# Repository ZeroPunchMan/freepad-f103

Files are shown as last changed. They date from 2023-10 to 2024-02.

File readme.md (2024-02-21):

# 使用说明

## 校准步骤
```
1.松开全部按键和摇杆,长按配对键(USB插孔旁).
2.等LED出现呼吸灯效果,此时程序会等待摇杆和扳机稳定,并记录作为初始值.
3.一直等待至LED出现快速闪烁效果,此时表示初始值已记录完毕,开始记录边界值.
4.把左右扳机按到底部,同时把两个摇杆摇圈.
5.待LED变成呼吸灯效果后,再重复数次,短按A键并松开.
6.LED恢复常亮,校准完毕.
```

## 重置校准值
```
同上面校准步骤,但第4步改为如下操作:
4.按住Y键.
5.等LED恢复为常亮,校准值重置完毕.
```

## 升级固件步骤
```
1.拔掉手柄USB线.
2.按住配对键(USB插孔旁).
3.插入USB线.
4.观察到LED较慢闪烁,表明手柄已进入BOOT状态.
5.打开DFU软件,选择对应串口并打开.
6.选择APP固件及其签名,点击开始升级.
7.提示升级成功则完毕.
```

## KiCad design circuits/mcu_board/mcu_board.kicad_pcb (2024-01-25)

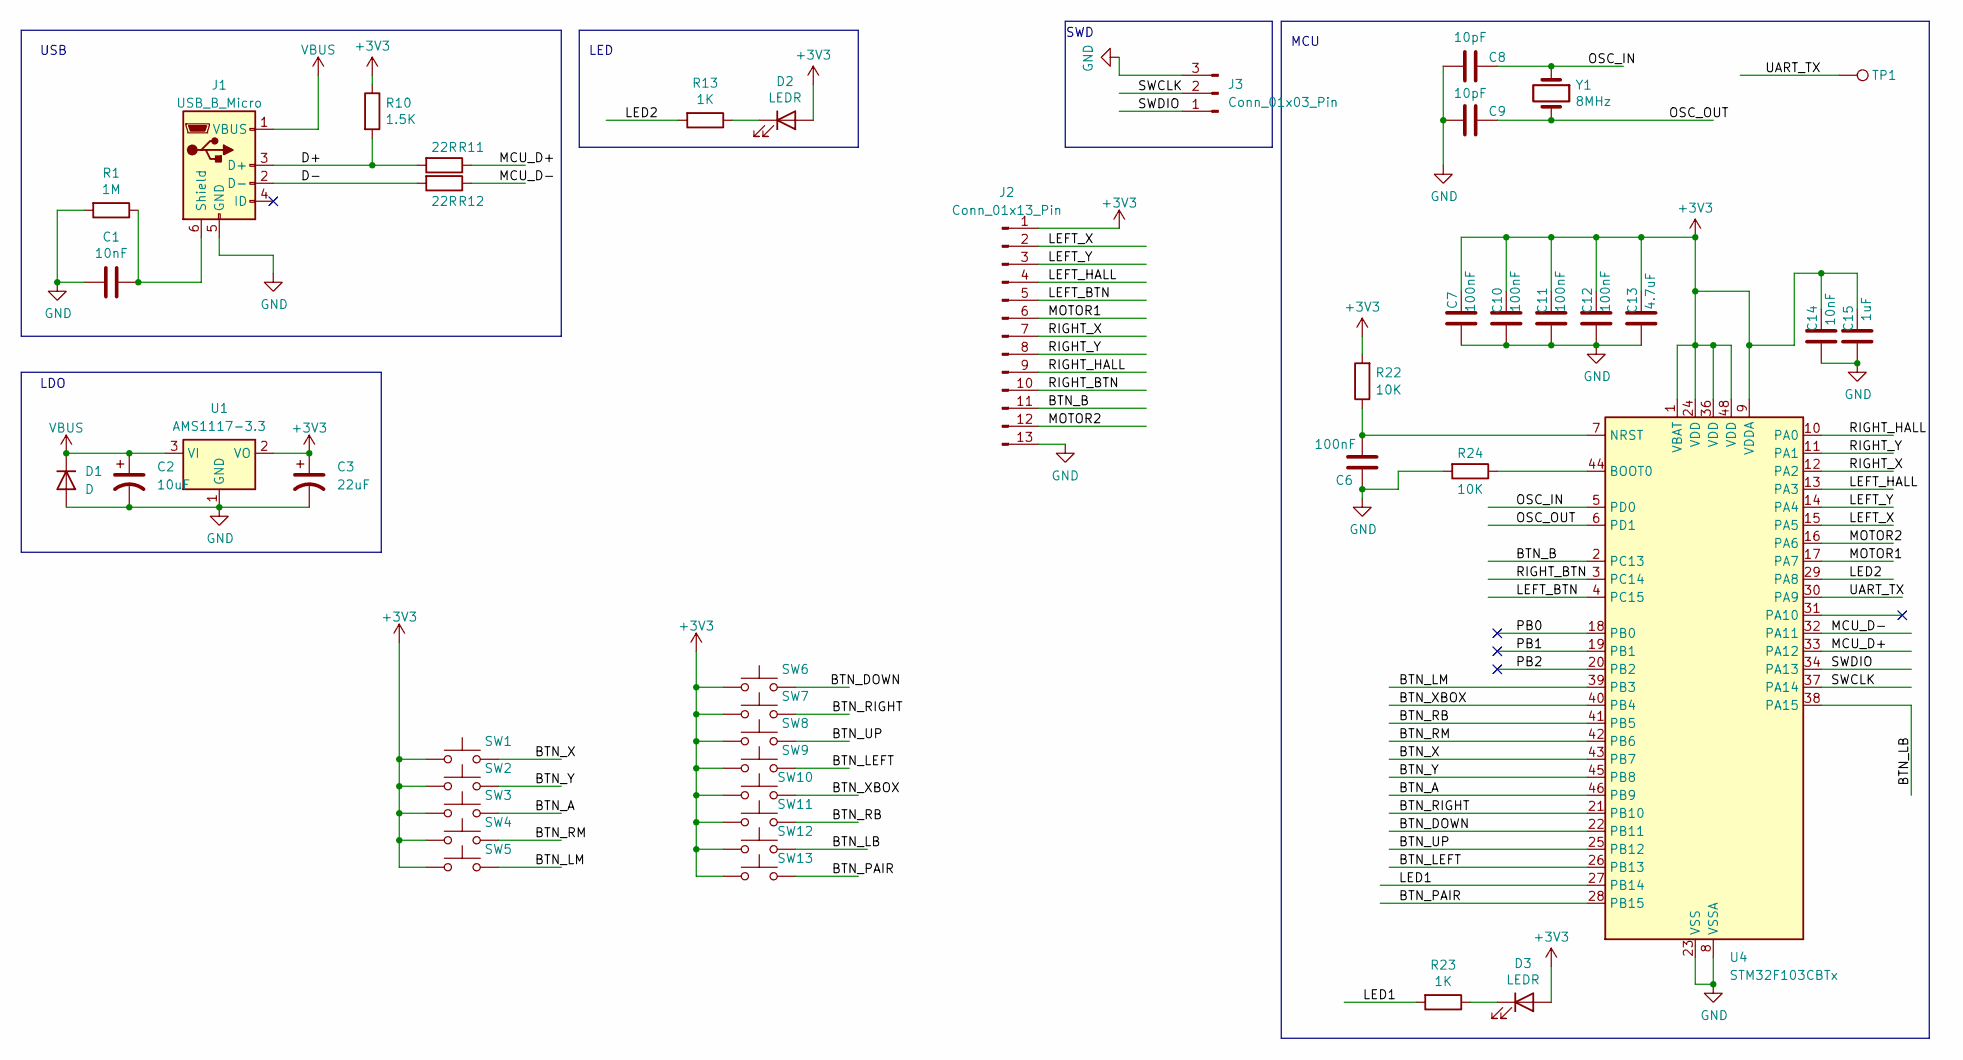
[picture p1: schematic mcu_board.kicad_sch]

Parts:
C1, C14: 10nF; C_0805_2012Metric_Pad1.18x1.45mm_HandSolder
C2: 10uF; C_1206_3216Metric_Pad1.33x1.80mm_HandSolder
C3: 22uF; C_1206_3216Metric_Pad1.33x1.80mm_HandSolder
C6, C7, C10, C11, C12: 100nF; C_0805_2012Metric_Pad1.18x1.45mm_HandSolder
C8, C9: 10pF; C_0805_2012Metric_Pad1.18x1.45mm_HandSolder
C13: 4.7uF; C_0805_2012Metric_Pad1.18x1.45mm_HandSolder
C15: 1uF; C_0805_2012Metric_Pad1.18x1.45mm_HandSolder
D1: D; D_2010_5025Metric_Pad1.52x2.65mm_HandSolder
D2, D3: LEDR; LED_0805_2012Metric_Pad1.15x1.40mm_HandSolder
J1: USB_B_Micro; USB_MICRO
J2: Conn_01x13_Pin; Molex_200528-0130_1x13-1MP_P1.00mm_Horizontal
J3: Conn_01x03_Pin; PinHeader_1x03_P2.54mm_Vertical
R1: 1M; R_0805_2012Metric_Pad1.20x1.40mm_HandSolder
R10: 1.5K; R_0805_2012Metric_Pad1.20x1.40mm_HandSolder
R11, R12: 22R; R_0805_2012Metric_Pad1.20x1.40mm_HandSolder
R13, R23: 1K; R_0805_2012Metric_Pad1.20x1.40mm_HandSolder
R22, R24: 10K; R_0805_2012Metric_Pad1.20x1.40mm_HandSolder
SW1, SW2, SW3, SW4, SW5: SW_Push; touch
SW6, SW7, SW8, SW9: SW_Push; touch-dpad
SW10: SW_Push; touch-xbox
SW11, SW12: SW_Push; click_lbrb
SW13: SW_Push; click_pair
TP1: TestPoint; TestPoint_Pad_1.0x1.0mm
U1: AMS1117-3.3; SOT-223-3_TabPin2
U4: STM32F103CBTx; LQFP-48_7x7mm_P0.5mm
Y1: 8MHz; Crystal_SMD_5032-2Pin_5.0x3.2mm_HandSoldering

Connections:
+3V3: C3.1, C7.1, C10.1, C11.1, C12.1, C13.1, C14.1, C15.1, D2.2 (A), D3.2 (A), J2.1, R10.1, R22.2, SW1.1, SW2.1, SW3.1, SW4.1, SW5.1, SW6.1, SW7.1, SW8.1, SW9.1, SW10.1, SW11.1, SW12.1, SW13.1, U1.2 (VO), U4.1 (VBAT), U4.9 (VDDA), U4.24 (VDD), U4.36 (VDD), U4.48 (VDD)
/BTN_A: SW3.2, U4.46 (PB9)
/BTN_B: J2.11, U4.2 (PC13)
/BTN_DOWN: SW6.2, U4.22 (PB11)
/BTN_LB: SW12.2, U4.38 (PA15)
/BTN_LEFT: SW9.2, U4.26 (PB13)
/BTN_LM: SW5.2, U4.39 (PB3)
/BTN_PAIR: SW13.2, U4.28 (PB15)
/BTN_RB: SW11.2, U4.41 (PB5)
/BTN_RIGHT: SW7.2, U4.21 (PB10)
/BTN_RM: SW4.2, U4.42 (PB6)
/BTN_UP: SW8.2, U4.25 (PB12)
/BTN_X: SW1.2, U4.43 (PB7)
/BTN_XBOX: SW10.2, U4.40 (PB4)
/BTN_Y: SW2.2, U4.45 (PB8)
/D+: J1.3 (D+), R10.2, R11.2
/D-: J1.2 (D-), R12.2
/LED1: R23.2, U4.27 (PB14)
/LED2: R13.2, U4.29 (PA8)
/LEFT_BTN: J2.5, U4.4 (PC15)
/LEFT_HALL: J2.4, U4.13 (PA3)
/LEFT_X: J2.2, U4.15 (PA5)
/LEFT_Y: J2.3, U4.14 (PA4)
/MCU_D+: R11.1, U4.33 (PA12)
/MCU_D-: R12.1, U4.32 (PA11)
/MOTOR1: J2.6, U4.17 (PA7)
/MOTOR2: J2.12, U4.16 (PA6)
/OSC_IN: C8.1, U4.5 (PD0), Y1.1
/OSC_OUT: C9.1, U4.6 (PD1), Y1.2
/PB0: U4.18 (PB0)
/PB1: U4.19 (PB1)
/PB2: U4.20 (PB2)
/RIGHT_BTN: J2.10, U4.3 (PC14)
/RIGHT_HALL: J2.9, U4.10 (PA0)
/RIGHT_X: J2.7, U4.12 (PA2)
/RIGHT_Y: J2.8, U4.11 (PA1)
/SWCLK: J3.2, U4.37 (PA14)
/SWDIO: J3.1, U4.34 (PA13)
/UART_TX: TP1.1, U4.30 (PA9)
GND: C1.2, C2.2, C3.2, C6.2, C7.2, C8.2, C9.2, C10.2, C11.2, C12.2, C13.2, C14.2, C15.2, D1.2 (A), J1.5 (GND), J2.13, J3.3, R1.2, R24.2, U1.1 (GND), U4.8 (VSSA), U4.23 (VSS), U4.35 (VSS), U4.47 (VSS)
unnamed: D2.1 (K), R13.1
unnamed: D3.1 (K), R23.1
unnamed: C1.1, J1.6 (Shield), R1.1
unnamed: R24.1, U4.44 (BOOT0)
unnamed: C6.1, R22.1, U4.7 (NRST)
VBUS: C2.1, D1.1 (K), J1.1 (VBUS), U1.3 (VI)

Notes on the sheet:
LDO
USB
SWD
MCU
LED

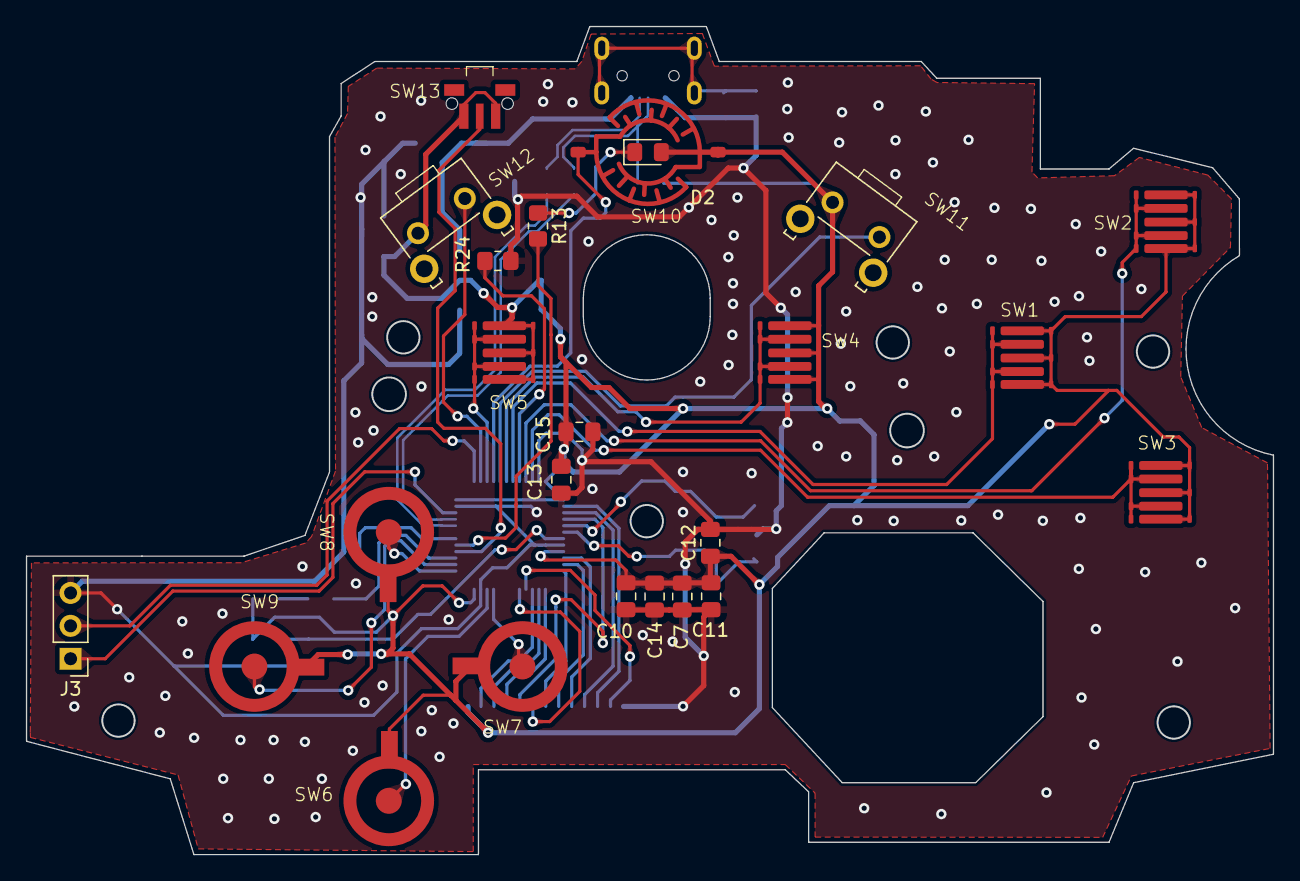
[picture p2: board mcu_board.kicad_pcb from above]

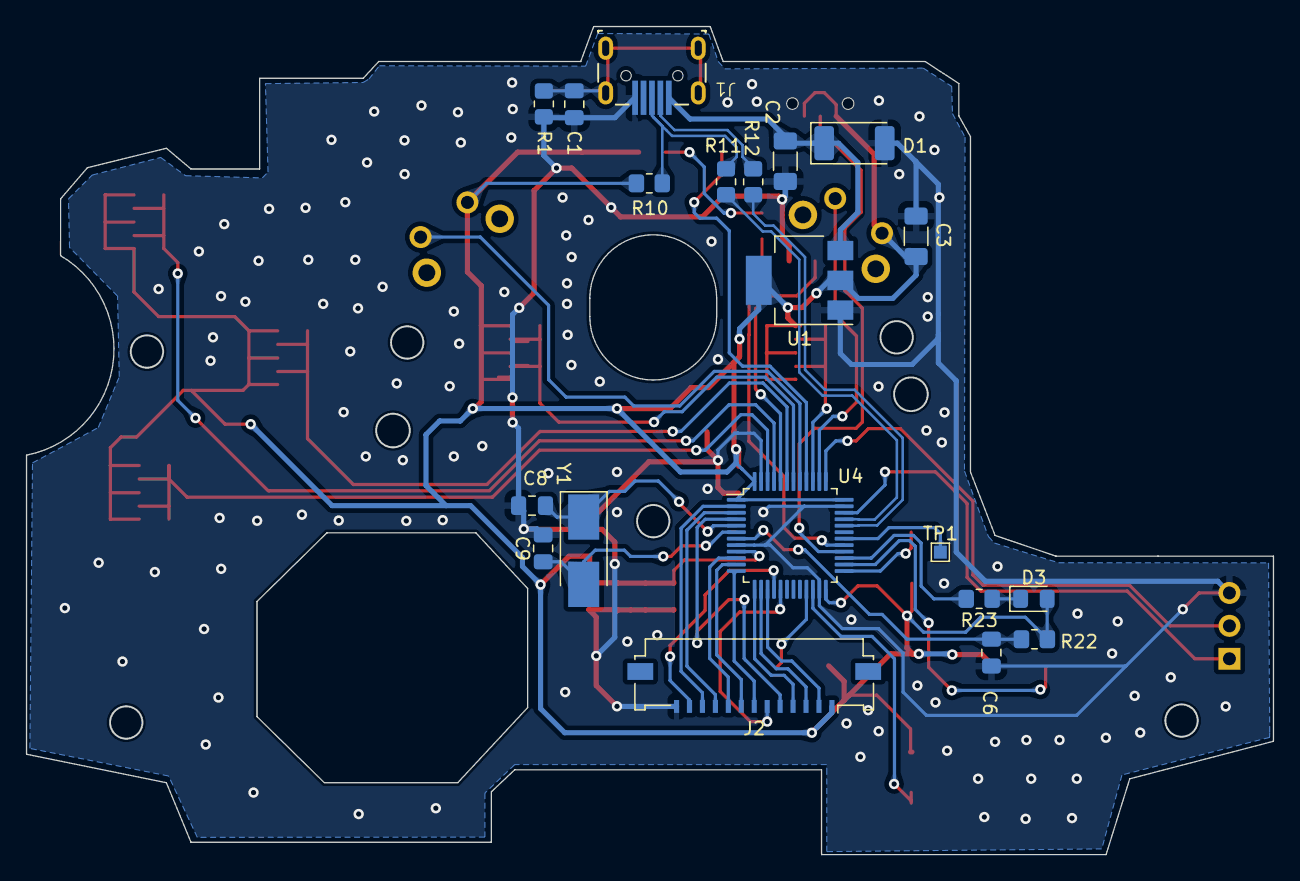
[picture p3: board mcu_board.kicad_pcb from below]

Board: 2 copper layers, 96.3 x 63.9 mm, 44 parts (20 on the bottom side), 43 nets.

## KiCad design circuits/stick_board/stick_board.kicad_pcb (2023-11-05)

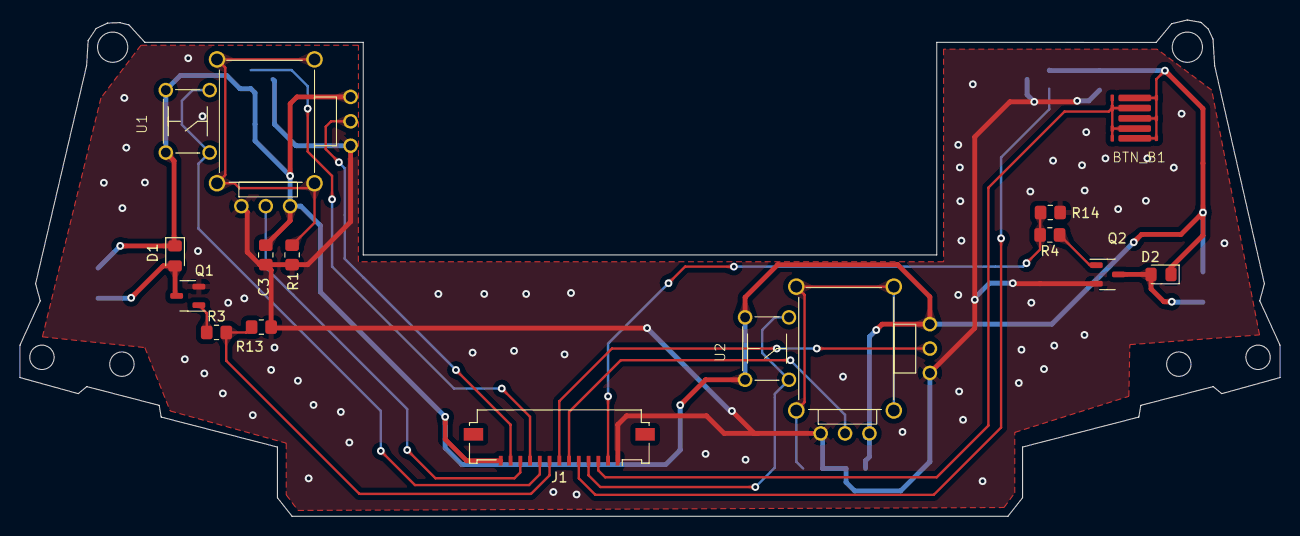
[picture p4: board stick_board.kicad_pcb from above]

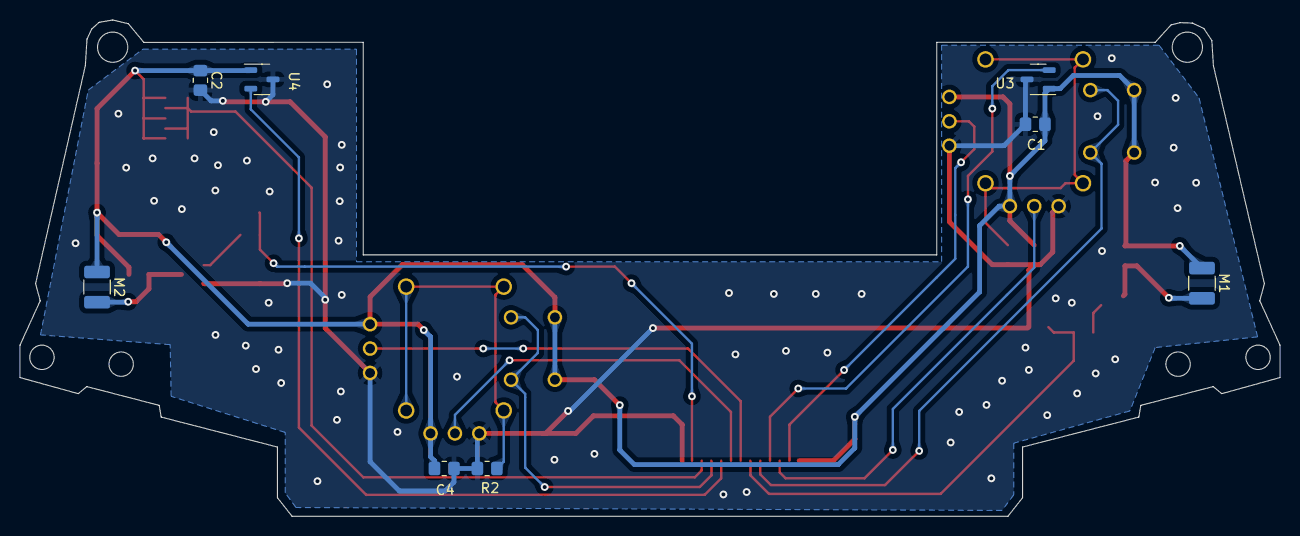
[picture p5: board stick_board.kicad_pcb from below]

Board: 2 copper layers, 129.2 x 50.9 mm, 22 parts (8 on the bottom side), 19 nets.

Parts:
BTN_B1: SW_PUSH; touch
C1, C2, C3, C4: 100nF; R_0805_2012Metric_Pad1.20x1.40mm_HandSolder
D1, D2: D; D_0805_2012Metric_Pad1.15x1.40mm_HandSolder
J1: Conn_01x13_Pin; Molex_200528-0130_1x13-1MP_P1.00mm_Horizontal
M1, M2: Motor_DC; R_1210_3225Metric_Pad1.30x2.65mm_HandSolder
Q1, Q2: AO3400A; SOT-23-3
R1, R2: 1M; R_0805_2012Metric_Pad1.20x1.40mm_HandSolder
R3, R4: 1K; R_0805_2012Metric_Pad1.20x1.40mm_HandSolder
R13, R14: 10K; R_0805_2012Metric_Pad1.20x1.40mm_HandSolder
U1, U2: GULI
U3, U4: DRV5055A1xDBZxQ1; SOT-23-3

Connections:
+3V3: BTN_B1.1, C1.1, C2.1, C3.1, C4.1, D1.1 (K), D2.1 (K), J1.13, M1.1 (+), M2.1 (+), U1.2 (VDD), U1.5 (SW_2), U2.2 (VDD), U2.5 (SW_2), U3.1 (VCC), U4.1 (VCC)
/BTN_B: BTN_B1.2, J1.3
/LEFT_BTN: J1.9, U1.4 (SW_1)
/LEFT_HALL: J1.10, U3.2 (OUT)
/LEFT_X: J1.12, U1.7 (X)
/LEFT_Y: J1.11, U1.6 (Y)
/MOTOR1: J1.8, R3.2, R13.2
/MOTOR2: J1.2, R4.2, R14.2
/RIGHT_BTN: J1.4, U2.4 (SW_1)
/RIGHT_HALL: J1.5, U4.2 (OUT)
/RIGHT_X: J1.7, U2.7 (X)
/RIGHT_Y: J1.6, U2.6 (Y)
GND: C1.2, C2.2, C3.2, C4.2, J1.1, Q1.2 (S), Q2.2 (S), R1.1, R2.1, R13.1, R14.1, U1.1 (GND), U2.1 (GND), U3.3 (GND), U4.3 (GND)
unnamed: D1.2 (A), M1.2 (-), Q1.3 (D)
unnamed: D2.2 (A), M2.2 (-), Q2.3 (D)
unnamed: Q1.1 (G), R3.1
unnamed: Q2.1 (G), R4.1
unnamed: R1.2, U1.3 (Shield)
unnamed: R2.2, U2.3 (Shield)

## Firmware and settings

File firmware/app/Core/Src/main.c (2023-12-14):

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
/* Includes ------------------------------------------------------------------*/
#include "main.h"
#include "adc.h"
#include "dma.h"
#include "tim.h"
#include "usart.h"
#include "usb_device.h"
#include "gpio.h"

/* USER CODE BEGIN Includes */
#include "systime.h"
#include "cl_log.h"
#include "cl_event_system.h"
#include "pad_func.h"
#include "led.h"
#include "button.h"
/* USER CODE END Includes */


void SystemClock_Config(void);
/* USER CODE BEGIN 0 */
static void UsbFakePlug(void)
{
  LL_APB2_GRP1_EnableClock(LL_APB2_GRP1_PERIPH_GPIOA);
  LL_GPIO_ResetOutputPin(GPIOA, LL_GPIO_PIN_12);

  LL_GPIO_InitTypeDef GPIO_InitStruct = {0};
  GPIO_InitStruct.Pin = LL_GPIO_PIN_12;
  GPIO_InitStruct.Mode = LL_GPIO_MODE_OUTPUT;
  GPIO_InitStruct.Speed = LL_GPIO_SPEED_FREQ_LOW;
  GPIO_InitStruct.OutputType = LL_GPIO_OUTPUT_OPENDRAIN;
  GPIO_InitStruct.Pull = LL_GPIO_PULL_UP;
  LL_GPIO_Init(GPIOA, &GPIO_InitStruct);

  LL_GPIO_ResetOutputPin(GPIOA, LL_GPIO_PIN_12);
  HAL_Delay(100);
  LL_GPIO_SetOutputPin(GPIOA, LL_GPIO_PIN_12);
}
/* USER CODE END 0 */

/**
  * @brief  The application entry point.
  * @retval int
  */
int main(void)
{
  /* USER CODE BEGIN 1 */
  CL_EventSysInit();
  /* USER CODE END 1 */

  /* MCU Configuration--------------------------------------------------------*/

  /* Reset of all peripherals, Initializes the Flash interface and the Systick. */
  HAL_Init();

  /* Configure the system clock */
  SystemClock_Config();

  /* USER CODE BEGIN SysInit */
  UsbFakePlug();
  /* USER CODE END SysInit */

  /* Initialize all configured peripherals */
  MX_GPIO_Init();
  MX_DMA_Init();
  MX_USART1_UART_Init();
  MX_USB_DEVICE_Init();
  MX_ADC1_Init();
  MX_TIM3_Init();
  MX_TIM1_Init();
  /* USER CODE BEGIN 2 */
  HAL_TIM_PWM_Start(&htim3, TIM_CHANNEL_1);
  HAL_TIM_PWM_Start(&htim3, TIM_CHANNEL_2);
  HAL_TIM_PWM_Start(&htim1, TIM_CHANNEL_1);
  /* USER CODE END 2 */

  /* Infinite loop */
  /* USER CODE BEGIN WHILE */
  Button_Init();
  Led_Init();
  PadFunc_Init();
  while (1)
  {
    Button_Process();
    Led_Process();
    PadFunc_Process();
    /* USER CODE END WHILE */

    /* USER CODE BEGIN 3 */
    static uint32_t lastTime = 0;
    if (SysTimeSpan(lastTime) >= 1000)
    {
      lastTime = GetSysTime();
      // CL_LOG_INFO("app2: %us", lastTime / 1000);
    }
  }
  /* USER CODE END 3 */
}

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


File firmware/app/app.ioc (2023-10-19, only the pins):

Mcu.UserName=STM32F103CBTx
PA0-WKUP.Signal=ADCx_IN0
PA1.Signal=ADCx_IN1
PA10.Signal=USART1_RX
PA11.Signal=USB_DM
PA12.Signal=USB_DP
PA15.Signal=GPIO_Input
PA2.Signal=ADCx_IN2
PA3.Signal=ADCx_IN3
PA4.Signal=ADCx_IN4
PA5.Signal=ADCx_IN5
PA6.Signal=S_TIM3_CH1
PA7.Signal=S_TIM3_CH2
PA8.Signal=S_TIM1_CH1
PA9.Signal=USART1_TX
PB10.Signal=GPIO_Input
PB11.Signal=GPIO_Input
PB12.Signal=GPIO_Input
PB13.Signal=GPIO_Input
PB14.Signal=GPIO_Output
PB15.Signal=GPIO_Input
PB3.Signal=GPIO_Input
PB4.Signal=GPIO_Input
PB5.Signal=GPIO_Input
PB6.Signal=GPIO_Input
PB7.Signal=GPIO_Input
PB8.Signal=GPIO_Input
PB9.Signal=GPIO_Input
PC13-TAMPER-RTC.Signal=GPIO_Input
PC14-OSC32_IN.Signal=GPIO_Input
PC15-OSC32_OUT.Signal=GPIO_Input
PD0-OSC_IN.Signal=RCC_OSC_IN
PD1-OSC_OUT.Signal=RCC_OSC_OUT

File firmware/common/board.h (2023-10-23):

#pragma once

#include "main.h"

#define GPIO_APB (LL_APB2_GRP1_PERIPH_GPIOB)

#define STA_LED_PROT (GPIOB)
#define STA_LED_PIN (LL_GPIO_PIN_14)

//**************按键****************
#define BTN_B_PORT (GPIOC)
#define BTN_B_PIN (LL_GPIO_PIN_13)

#define BTN_RSTICK_PORT (GPIOC)
#define BTN_RSTICK_PIN (LL_GPIO_PIN_14)

#define BTN_LSTICK_PORT (GPIOC)
#define BTN_LSTICK_PIN (LL_GPIO_PIN_15)

#define BTN_LMENU_PORT (GPIOB)
#define BTN_LMENU_PIN (LL_GPIO_PIN_3)

#define BTN_XBOX_PORT (GPIOB)
#define BTN_XBOX_PIN (LL_GPIO_PIN_4)

#define BTN_RB_PORT (GPIOB)
#define BTN_RB_PIN (LL_GPIO_PIN_5)

#define BTN_RMENU_PORT (GPIOB)
#define BTN_RMENU_PIN (LL_GPIO_PIN_6)

#define BTN_X_PORT (GPIOB)
#define BTN_X_PIN (LL_GPIO_PIN_7)

#define BTN_Y_PORT (GPIOB)
#define BTN_Y_PIN (LL_GPIO_PIN_8)

#define BTN_A_PORT (GPIOB)
#define BTN_A_PIN (LL_GPIO_PIN_9)

#define BTN_RIGHT_PORT (GPIOB)
#define BTN_RIGHT_PIN (LL_GPIO_PIN_10)

#define BTN_DOWN_PORT (GPIOB)
#define BTN_DOWN_PIN (LL_GPIO_PIN_11)

#define BTN_UP_PORT (GPIOB)
#define BTN_UP_PIN (LL_GPIO_PIN_12)

#define BTN_LEFT_PORT (GPIOB)
#define BTN_LEFT_PIN (LL_GPIO_PIN_13)

#define BTN_PAIR_PORT (GPIOB)
#define BTN_PAIR_PIN (LL_GPIO_PIN_15)

#define BTN_LB_PORT (GPIOA)
#define BTN_LB_PIN (LL_GPIO_PIN_15)

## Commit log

2023-09-01 串口打印日志,未测试
2023-09-01 clib 配置; systime计时
2023-09-03 comm收发,未测试
2023-09-03 flash 报错
2023-09-03 comm初步测试ok
2023-09-03 dfu签名,不用备份区
2023-09-03 boot 初步完成,未测试
2023-09-03 app打印ok
2023-09-03 修改app启动地址
2023-09-03 增加app跳转判断
2023-09-04 升级协议初步ok
2023-09-04 boot 加上led
2023-09-04 hid 枚举成功
2023-09-04 单个按键测试ok
2023-09-05 boot vid pid string
2023-09-06 调整flash布局,增加一页存储pad参数
2023-09-06 增加pad_func
2023-09-06 out report接收
2023-09-07 hc165逻辑未实现
2023-09-07 加入adc和pwm
2023-09-08 HC165写完,未测试
2023-09-08 usb配置
2023-09-08 adc-dma中断触发了2次
2023-09-08 adc改用ll库,未完成
2023-09-08 adc dma中断
2023-09-08 关USB低功耗
2023-09-08 关usb low power
2023-09-09 按键扫描ok
2023-09-10 adc 摇杆ok
2023-09-10 add circuits
    [stick_board.kicad_pcb, stick_board.kicad_sch]
2023-09-10 add mcu board
    [mcu_board.kicad_pcb, mcu_board.kicad_sch, stick_board.kicad_sch]
2023-09-10 usb footprint
2023-09-11 增加键值映射,未测试
2023-09-11 pwm和led初步测试ok
    [mcu_board.kicad_sch, stick_board.kicad_sch]
2023-09-11 button和cali未完成
2023-09-11 校准流程未完成
2023-09-12 完成校准流程,未测试
2023-10-07 360枚举成功
2023-10-07 修改序列化
2023-10-07 初步测试ok
2023-10-07 需改按键映射测试 需测试校准流程
2023-10-08 HC165处理
2023-10-08 重命名, 增加震动处理
2023-10-08 增加马达限流电阻
    [stick_board.kicad_sch]
2023-10-09 报告序列化测试ok
2023-10-09 测试板摇杆和按键映射测试ok
2023-10-09 校准流程和led测试ok，
2023-10-11 layout 23.10.11
    [stick_board.kicad_pcb]
2023-10-14 layout 摇杆板轮廓
    [stick_board.kicad_pcb]
2023-10-14 layout 摇杆板布局ok
    [stick_board.kicad_pcb, stick_board.kicad_sch]
2023-10-14 layout 摇杆板完成
    [stick_board.kicad_pcb]
2023-10-15 layout 摇杆板优化马达驱动,增加覆铜过孔 MCU板改动
    [mcu_board.kicad_sch, stick_board.kicad_pcb, stick_board.kicad_sch]
2023-10-15 layout 增加摇杆板孔径
    [stick_board.kicad_pcb]
2023-10-15 mcu板 螺丝孔位置需验证
    [mcu_board.kicad_pcb, mcu_board.kicad_sch]
2023-10-15 layout MCU板大致形状
    [mcu_board.kicad_pcb]
2023-10-17 layout 增加lb/rb和pair按键封装 空间不够需精简电路
    [mcu_board.kicad_pcb, mcu_board.kicad_sch]
2023-10-17 更新mcu板原理图,改晶振封装
    [mcu_board.kicad_pcb, mcu_board.kicad_sch]
2023-10-18 mcu板极端精简电路
    [mcu_board.kicad_pcb, mcu_board.kicad_sch]
2023-10-19 laytou MCU板基本完成走线
    [mcu_board.kicad_pcb, mcu_board.kicad_sch]
2023-10-19 更新按键封装，不用开窗
    [mcu_board.kicad_pcb]
2023-10-19 移除两个马达PWM完成 移除HC165未完成
2023-10-19 按键逻辑修改完成,未测试
    [mcu_board.kicad_pcb, mcu_board.kicad_sch]
2023-10-19 GPIO改下拉
2023-10-19 状态led控制脚上拉
2023-10-19 stick板添加泪滴
    [stick_board.kicad_pcb]
2023-10-19 layout mcu板边界优化
    [mcu_board.kicad_pcb]
2023-10-20 摇杆板添加大量GND过孔
    [stick_board.kicad_pcb]
2023-10-21 螺丝孔位置确定，xbox键位置确定
    [mcu_board.kicad_pcb]
2023-10-21 dpad位置对准
    [mcu_board.kicad_pcb]
2023-10-21 剩下lb rb位置未确定
    [mcu_board.kicad_pcb]
2023-10-21 布局基本确定
    [mcu_board.kicad_pcb]
2023-10-21 layout未完成
    [mcu_board.kicad_pcb]
2023-10-22 MCU板layout完成
    [mcu_board.kicad_pcb, mcu_board.kicad_sch]
2023-10-22 减少stick板孔径
    [stick_board.kicad_pcb]
2023-10-22 缩小MCU板孔径
    [mcu_board.kicad_pcb]
2023-10-22 优化stick板边缘
    [stick_board.kicad_pcb]
2023-10-23 mcu板按键封装修改,添加泪滴和覆铜间距
    [mcu_board.kicad_pcb]
2023-10-23 调整mcu板覆铜间隙,消除警告
    [mcu_board.kicad_pcb]
2023-10-23 更新stick板按键封装
    [stick_board.kicad_pcb]
2023-10-23 修改单片机型号
    [mcu_board.kicad_pcb, mcu_board.kicad_sch, stick_board.kicad_pcb]
2023-10-23 修改按键映射
2023-10-25 按键检测有问题
2023-10-25 通过log测试按键ok
2023-10-25 更新摇杆板触摸键封装
    [stick_board.kicad_pcb]
2023-10-25 手柄板更新按键封装
    [mcu_board.kicad_pcb]
2023-10-25 mcu板更新封装
    [mcu_board.kicad_pcb]
2023-10-29 马达驱动增加栅极电阻
    [stick_board.kicad_pcb, stick_board.kicad_sch]
2023-10-29 更新按键封装
    [mcu_board.kicad_pcb]
2023-10-29 差手柄机械按键位置
    [mcu_board.kicad_pcb, stick_board.kicad_pcb]
2023-10-29 调整封装,待打样测试
    [mcu_board.kicad_pcb, stick_board.kicad_pcb]
2023-10-29 微调了LB RB位置
    [mcu_board.kicad_pcb]
2023-10-29 微调LB RB
    [mcu_board.kicad_pcb]
2023-10-29 微调MCU版USB信号线，增加过孔
    [mcu_board.kicad_pcb]
2023-11-01 修改ADC映射
2023-11-02 app启动地址修改
2023-11-03 LED PWM反向
2023-11-03 震动测试ok
2023-11-03 增加校准复位流程,未测试
2023-11-04 boot修改灯
2023-11-04 提高马达输出占空比
2023-11-04 mcu板排线座子位置优化
    [mcu_board.kicad_pcb]
2023-11-04 stick板去除马达限流电阻
    [stick_board.kicad_pcb, stick_board.kicad_sch]
2023-11-04 xbox按键需要加粗
    [mcu_board.kicad_pcb, stick_board.kicad_pcb]
2023-11-04 xbox按键线条加粗
    [mcu_board.kicad_pcb]
2023-11-04 优化mcu板尺寸
    [mcu_board.kicad_pcb]
2023-11-05 优化布局
    [mcu_board.kicad_pcb, stick_board.kicad_pcb]
2023-11-05 ldo位置优化
    [mcu_board.kicad_pcb]
2023-11-12 优化布局,准备用沉金工艺
    [mcu_board.kicad_pcb]
2023-11-12 过孔位置优化
    [mcu_board.kicad_pcb]
2023-11-15 增加APP版本信息
2023-11-15 boot中增加APP版本获取,未测试
2023-11-16 微调螺丝孔
    [mcu_board.kicad_pcb]
2023-11-16 增加泪滴
    [mcu_board.kicad_pcb]
2023-11-19 not done
    [mcu_board.kicad_pcb]
2023-11-19 优化元件位置,防止外壳挤压
    [mcu_board.kicad_pcb]
2023-11-20 晶振下移一点
    [mcu_board.kicad_pcb]
2023-11-28 增加readme说明操作步骤
2023-11-28 增加readme升级说明,注释todo未做的远程唤醒
2023-12-01 代码review问题修复
2023-12-08 微调电阻位置
    [mcu_board.kicad_pcb]
2023-12-13 更新log模块,未测试
2023-12-13 boot更新log模块
2023-12-13 更新log模块
2023-12-13 log增加换行
2023-12-14 精简log app
2023-12-14 精简log boot
2024-01-09 HID传输完成ep判断
2024-01-22 扳机插值改为立方根
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2024-01-25 改电容位置,避免碰到遥感帽
    [mcu_board.kicad_pcb]
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2024-03-05 1.上报时增加USB空闲判断,减少无用计算 2.增加摇杆修正测试,用来验证修正值的角度
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2024-09-27 修正log

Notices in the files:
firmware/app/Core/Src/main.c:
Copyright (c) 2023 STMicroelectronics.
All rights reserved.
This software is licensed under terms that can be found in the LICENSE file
